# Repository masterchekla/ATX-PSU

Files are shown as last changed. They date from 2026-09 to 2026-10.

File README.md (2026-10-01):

# DIY ATX Bench Power Supply

**Project 1 · Electronics Circuits Laboratory · 091013107**

| Name | Student ID |
|---|---|
| Sirawit Lila | 6809098660047 |
| Pichawee Rungwiboontikul | 6809107660067 |

## 1. Introduction

This was our first power supply project. As second-year students, we studied how an ATX power supply works and used it to build a supply for small circuit experiments. The project combines fixed outputs with an adjustable output in one box.

The fixed outputs are 12 V, 5 V and 3.3 V, with a common GND terminal. A ZK-4KX buck–boost module provides the adjustable output. We also added a 12 V cigarette-lighter power socket, a 5 V LED strip and two status LEDs, while retaining the original PSU fan. We worked together on the project.

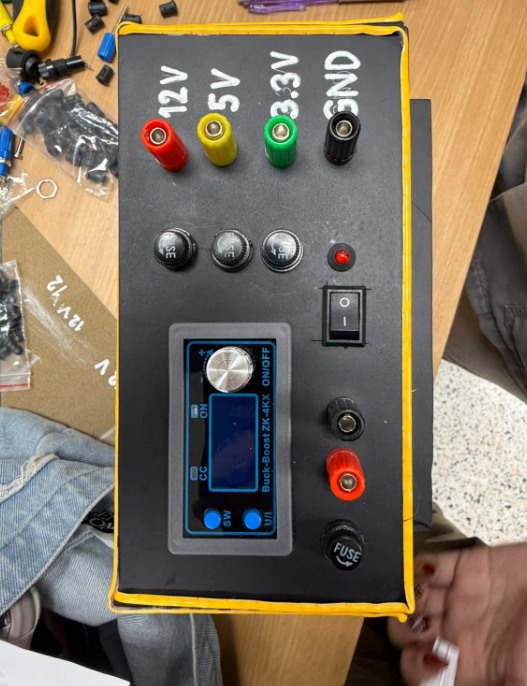
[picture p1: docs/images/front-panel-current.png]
Our power supply front panel


### Source PSU

We used a **PLENTY COMPUTER ATX500WS**, marked **MAX 500 W**. The rear inlet states **AC 230 V Only**. Its nameplate ratings are:

| Output | Current on label |
|---|---:|
| +3.3 V | 22 A |
| +5 V | 14 A |
| +12V1 | 13 A |
| +12V2 | 14 A |
| −12 V | 0.8 A |
| +5VSB | 2.5 A |

The +3.3 V and +5 V rails share a 130 W limit. These are source ratings; each panel branch is also limited by its own fuse, wire and connector. The [source PSU record](docs/source-psu.md) includes the label photographs and the +12V1 label calculation.

## 2. Objectives

- Use the ATX outputs to power small circuits.
- Add voltage adjustment and a current-limit setting using the ZK-4KX.
- Connect the output terminals, switch, indicators and three fixed-output fuses.
- Apply basic voltage, current, resistance and power calculations to the circuit.

## 3. Circuit operation

```mermaid
flowchart LR
    A[ATX PSU] --> B[12 V / 5 V / 3.3 V]
    B --> C[Three fuses]
    C --> D[Fixed output terminals]
    A --> E[12 V to ZK-4KX]
    E --> F[Adjustable output terminals]
    A --> G[12 V socket and 5 V strip]
    A --> H[Purple: green standby LED]
    A --> I[Gray: red power-good LED]
    J[PS_ON switch] --> A
```

### Fixed outputs and fuses

Each fixed positive terminal has its own fuse. F1 serves 12 V, F2 serves 5 V and F3 serves 3.3 V. The black GND terminal is the common return. These three fuses are connected only to the fixed-output branches. The other circuits take their supply directly from the PSU board outputs.

| Output | Front-panel terminal | Standard ATX wire |
|---|---|---|
| +12 V | Red | Yellow |
| +5 V | Yellow | Red |
| +3.3 V | Green | Orange |
| GND / COM | Black | Black |

The panel colors and ATX wire colors are different, so the voltage labels identify the outputs.

### Switch and indicators

The main switch connects the green PS_ON wire to COM to turn on the main outputs. Opening the switch turns them off. The purple +5VSB wire supplies the green standby LED. The gray PWR_OK wire supplies the red LED, which follows the PSU's power-good signal. Each LED has a 1 kΩ series resistor.

Standby power can remain active while the main switch is off. With this arrangement, the green LED can also stay on during main operation. The LED calculations and PWR_OK loading are discussed in Section 5.

### Adjustable output

The ZK-4KX uses the 12 V supply as its input. It can step the voltage up or down and lets us set a current limit. OUT+ connects directly to the positive terminal; the negative terminal connects to OUT−. There is no separate external fuse in this adjustable-output branch. Using OUT− keeps the load current in the module's current-measuring path. It does not electrically isolate the output from the PSU. See the [module instructions](https://aitendo3.sakura.ne.jp/aitendo_data/product_img/power/DC-DC/ZK-4KX/ZK-4KX.pdf) for operation.

### Socket, fan and lighting

J8 is a **12 V panel-mount cigarette-lighter power socket with a protective cap**. The circuit uses its centre contact for +12 V and its outer electrical contact for COM. It provides a connection for 12 V accessories. The original PSU fan provides airflow, and the 5 V LED strip provides lighting around the box.

### Schematic

The schematic shows the low-voltage wiring with the ATX supply on the left and the output terminals on the right. Wires connect the components directly; dots mark connected junctions. J1 groups equivalent ATX signals, with the standard pin numbers retained in the KiCad symbol. These identify connector signals, not physical board pads. The original fan is shown inside the PSU, and the LED returns connect to COM.

Circuit schematic

[KiCad schematic](hardware/diy_atx_psu.kicad_sch) · [Full-size drawing](docs/images/schematic/diy_atx_psu.svg) · [Wire and pin table](docs/wiring-and-protection.md)

## 4. Bill of materials

| Part | Quantity | Function |
|---|---:|---|
| PLENTY ATX500WS power supply | 1 | Fixed rails and standby supply; MAX 500 W label |
| ZK-4KX module | 1 | Adjustable voltage and current limit |
| Fixed output terminals | 4 | 12 V, 5 V, 3.3 V and GND |
| Adjustable output terminals | 2 | OUT+ and OUT− |
| Fixed-output fuses and panel holders | 3 | One per fixed positive output |
| Main switch | 1 | PS_ON control |
| Green LED and red LED | 1 each | Standby and power-good indication |
| 1 kΩ resistors | 2 | LED current control |
| 12 V cigarette-lighter power socket | 1 | Automotive accessory connection |
| Original PSU fan | Included in PSU | Airflow |
| 5 V LED strip | 1 assembly | Lighting |
| Enclosure, wires and mounting parts | 1 set | Assembly and connections |

[Component references](docs/bom.md)

## 5. Calculations

These calculations use the assumptions shown below. The calculated values are not measured test results.

### LED current and resistor power

For a series resistor, `I = (Vs − Vf) / R` and `P = I²R`.

| LED | Calculation assumptions | Calculated current | Resistor power |
|---|---|---:|---:|
| Green | Vs = 5 V, Vf = 2.1 V, R = 1 kΩ | 2.9 mA | 8.41 mW |
| Red | Ideal PWR_OK = 5 V, Vf = 2.0 V, R = 1 kΩ | 3.0 mA | 9.00 mW |

For example, the green LED current is `(5 − 2.1) / 1000 = 0.0029 A`. Both calculated resistor powers are well below 0.25 W.

The gray PWR_OK wire is a status signal. Intel specifies its high voltage with a 0.2 mA load. Our red-LED example gives 3 mA, which is above that specified test load. The actual LED current depends on how much the signal voltage drops under load. Seeing the LED light up does not tell us whether PWR_OK stays within its voltage specification. [Intel PWR_OK specification](https://edc.intel.com/content/www/ca/fr/design/ipla/software-development-platforms/client/platforms/alder-lake-desktop/atx-version-3-0-multi-rail-desktop-platform-po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)

### Converter input current

Using an example output of 15 W and an assumed efficiency of 85%:

`Iin = Pout / (efficiency × Vin)`

At 12 V input, `Iin = 15 / (0.85 × 12) = 1.471 A`.

At 11.2 V input, `Iin = 15 / (0.85 × 11.2) = 1.576 A`.

The input power is `15 / 0.85 = 17.647 W`, giving an estimated loss of `2.647 W`. This shows why input current and cooling matter when using a buck–boost converter.

### Wire resistance and voltage drop

For an example with 0.75 mm² copper wire, 0.5 m outward and 0.5 m returning, use copper resistivity `0.0175 Ω·mm²/m` at 20 °C:

`Rloop = 0.0175 × 1.0 / 0.75 = 0.0233 Ω`

At an assumed 3 A, `Vdrop = IR = 0.070 V` and `Ploss = I²R = 0.210 W`.

Contacts and fuses add resistance. The common return carries the combined return current from the connected fixed-output loads.

### Fuse selection example

For an assumed 1 A continuous load per fixed output and a preliminary 75% loading factor:

`Minimum nominal rating = 1 / 0.75 = 1.33 A`

A 2 A fuse is one possible choice for this example. The final choice also depends on the wire, holder, temperature, startup current and the fuse's ability to interrupt a DC fault. This example does not identify the fuses installed in our box, so the schematic labels them F1–F3 without giving an ampere rating. [Fuse selection reference](https://www.littelfuse.com/assetdocs/fuseology-selection-guide?assetguid=fa4aa360-f6c4-4eec-88a6-3d7ec3fe57d5)

[Detailed calculations](docs/calculations.md)

## 6. Construction

The front panel holds the fixed terminals, adjustable terminals, fuse holders, main switch and ZK-4KX controls. The socket and LED strip complete the assembly; cooling uses the original PSU fan. Internal photographs show the construction stage; the project enclosure is now closed.

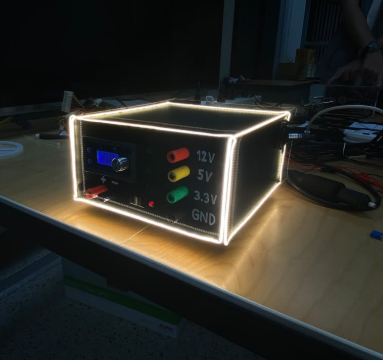
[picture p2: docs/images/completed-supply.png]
Completed supply in operation


[Construction photographs](docs/evidence-register.md) · [Front-panel arrangement](docs/mechanical.md)

## 7. Testing

The following table summarizes the team's reported functional test results. Results are recorded on a pass/fail basis.

| Check | Result |
|---|---|
| Unpowered wiring, polarity and continuity | PASS |
| PS_ON switching and standby/main indication | PASS |
| Startup, repeated-start and no-load operation | PASS |
| Fixed-output operation under load | PASS |
| Adjustable-output operation and current-limit check | PASS |
| Voltage-drop check | PASS |
| Ripple check | PASS |
| Thermal observation | PASS |
| Socket, fan and LED strip operation | PASS |
| Shutdown | PASS |

[Test summary and scope](docs/testing.md)

## 8. Discussion

PS_ON, +5VSB and PWR_OK have different jobs. PS_ON turns on the main outputs, +5VSB supplies standby power, and PWR_OK indicates that the main outputs are ready. The terminal colors on our panel differ from the ATX wire colors, so we use the voltage labels when connecting a load.

The 1 kΩ resistors limit LED current. F1–F3 protect the three fixed-output branches. The adjustable output has no separate external branch fuse. The socket and LED strip have no separate external branch fuses. These branches and the direct PWR_OK LED connection need to be considered when assessing the circuit's protection. The adjustable output is also limited by input power, conversion losses and cooling.

## 9. Operation

1. Start with the main switch off and the adjustable output disabled.
2. Connect AC and observe the green standby indicator.
3. Turn on the main switch and check the selected output voltage.
4. For the adjustable output, set voltage and current limit before connecting a load.
5. Use the labelled terminals and keep the fan and vents clear.
6. After use, disable the outputs, turn off the main switch and disconnect AC.

Disconnect AC and allow stored energy to discharge before changing wiring or fuses. Replace a fuse with a matching type and rating after finding the cause of the fault. The socket is used for accessories; a lighter heating element is outside the project application. [Operating procedure](docs/operation.md)

## 10. Conclusion

We built a bench power supply with 12 V, 5 V and 3.3 V terminals, an adjustable output and a 12 V accessory socket. The functional checks are summarized in Section 7. This first project gave us practice in wiring, mounting parts and calculating current and power. We worked together on the assembly and learned how the ATX control wires and adjustable module work.

## References

- Course handout: *Project 1 – ATX Bench Power Supply*, Chapter 3, Electronics Circuits Laboratory 091013107.
- Intel: [PWR_OK specification](https://edc.intel.com/content/www/ca/fr/design/ipla/software-development-platforms/client/platforms/alder-lake-desktop/atx-version-3-0-multi-rail-desktop-platform-po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) and [ATX voltage regulation](https://edc.intel.com/content/www/us/en/design/ipla/software-development-platforms/client/platforms/alder-lake-desktop/atx-version-3-0-multi-rail-desktop-platform-po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).
- Parts Express: [ZK-4KX module instructions](https://aitendo3.sakura.ne.jp/aitendo_data/product_img/power/DC-DC/ZK-4KX/ZK-4KX.pdf).
- Littelfuse: [Fuseology selection guide](https://www.littelfuse.com/assetdocs/fuseology-selection-guide?assetguid=fa4aa360-f6c4-4eec-88a6-3d7ec3fe57d5).

[Team contribution](docs/contributions.md) · [Project files](docs/repository-guide.md)

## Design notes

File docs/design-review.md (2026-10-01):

# Circuit Discussion

## Outputs and return paths

The fixed outputs share COM. The adjustable load returns through U1 OUT− so its current follows the module's sensing path. The drawing uses standard ATX signal names and the described wiring arrangement.

## Indicators

Green uses +5VSB through 1 kΩ. Red uses PWR_OK through 1 kΩ. An ideal 5 V red-LED supply with a 2 V forward drop gives 3 mA. Intel specifies the PWR_OK high level at a 0.2 mA sourcing load, so this direct-drive arrangement depends on the PSU's particular driver. The signal's loaded voltage determines the actual LED current. [Intel specification](https://edc.intel.com/content/www/ca/fr/design/ipla/software-development-platforms/client/platforms/alder-lake-desktop/atx-version-3-0-multi-rail-desktop-platform-po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)

## Protection

F1–F3 serve the three fixed positive outputs only. The adjustable output connects directly from OUT+ to its positive terminal and has no separate external fuse. The converter input, socket and strip connect to PSU outputs; the fan is part of the original PSU assembly. Protection must be coordinated with each branch's wire and components; the main source's protection does not by itself establish protection for every smaller wire. The fuse example uses an assumed 1 A load per fixed branch.

## Conversion losses

The converter input current follows input power. At an assumed 85% efficiency, a 15 W output requires 17.647 W input and produces about 2.647 W loss. Cooling and the combined load on the source therefore affect usable output power.

## Scope of the drawing

The schematic represents low-voltage distribution and control. The PSU and converter are functional blocks. Their internal circuits and mains wiring are outside this drawing. Connector and module symbols describe connectivity; ERC does not model the PWR_OK driver's current capability or fuse-clearing energy.

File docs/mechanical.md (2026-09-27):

# Mechanical Arrangement

The front panel groups the fixed terminals above the adjustable-output controls. Three fuse holders serve the fixed outputs. The main switch and status indicator provide the panel controls, while the fan and LED strip support airflow and lighting.

Current front panel

Front-panel arrangement

*Layout illustration based on the construction photographs; not to scale.*

The enclosure is closed for operation. Insulation around terminal backs, secure wire routing, strain relief and clearance from fan blades are important construction details. The adjustable return is routed to the module OUT−, and the shared COM path carries the combined fixed-output return current.

[Construction photographs](evidence-register.md)

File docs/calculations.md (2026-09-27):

# Calculation Notes

These examples use the assumptions stated below. The functional test summary is in [Testing](testing.md).

## 1. LED resistors

`I = (Vs − Vf) / R` and `PR = (Vs − Vf)² / R`.

Nominal R = 1 kΩ. Assume Vf = 2.1 V for green and 2.0 V for red. The tolerance examples use R = 950 Ω and Vf = 1.8 V, with 5.25 V for standby and an ideal 5 V for PWR_OK.

| Example | Current (mA) | Resistor power (mW) |
|---|---:|---:|
| Green, nominal 5 V | 2.9000 | 8.4100 |
| Red, ideal 5 V signal | 3.0000 | 9.0000 |
| Red, ideal 2.4 V signal | 0.4000 | 0.1600 |
| Red, tolerance example | 3.3684 | 10.7789 |
| Green, tolerance example | 3.6316 | 12.5289 |

A 0.25 W resistor has ample power margin in these examples. The red-LED figures assume an ideal signal voltage. Intel specifies PWR_OK high at a 0.2 mA sourcing load; the ideal 5 V example demands 3 mA, or 15 times that condition. Actual LED current depends on the PSU driver and loaded voltage. The 0.2 mA specification is a guaranteed test condition, not an absolute damage limit. [PWR_OK specification](https://edc.intel.com/content/www/ca/fr/design/ipla/software-development-platforms/client/platforms/alder-lake-desktop/atx-version-3-0-multi-rail-desktop-platform-po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)

## 2. Converter input and loss

Assume Pout = 15 W and efficiency = 85%.

`Pin = Pout / efficiency = 17.647 W`

At Vin = 11.2 V, `Iin = Pin / Vin = 1.576 A`.

At Vin = 12 V, `Iin = 15 / (0.85 × 12) = 1.471 A`.

`Ploss = Pin − Pout = 2.647 W`.

These are steady-state examples. Startup current and idle consumption are separate contributions. Usable output also depends on source, wire, module and thermal ratings.

## 3. Wire voltage drop

Assume copper resistivity = 0.0175 Ω·mm²/m at 20 °C, cross-section = 0.75 mm², and length = 0.5 m each way. The total circuit length is 1.0 m.

`Rloop = 0.0175 × 1.0 / 0.75 = 0.023333 Ω`

At an assumed 3 A:

- Voltage drop = 0.070 V.
- Wire power loss = 0.210 W.
- Drop relative to 3.3 V = 2.12%.

Contact resistance and fuse resistance add to this result. Wire ampacity also depends on insulation, temperature, routing and termination quality.

## 4. Fixed-output fuse example

Assume a continuous load of 1 A per fixed output and a preliminary loading factor of 75%.

| Branch | Assumed current (A) | I / 0.75 (A) | Calculation candidate (A) |
|---|---:|---:|---:|
| F1 | 1.00 | 1.333 | 2 |
| F2 | 1.00 | 1.333 | 2 |
| F3 | 1.00 | 1.333 | 2 |

The 2 A values belong to this selection example, rather than a fitted-fuse record. The exact part must coordinate with the wire, holder, load, ambient temperature and fault current. See [Wiring and Protection](wiring-and-protection.md).

## 5. Source current budget

`I12 = I12_terminal + Isocket + Iconverter_input`

`I5 = I5_terminal + Istrip`

`I3.3 = I3.3_terminal`

`I5VSB = Igreen_LED + other standby loads`

The original fan belongs to the PSU internal circuit and is outside the external branch-current sum. The red LED loads PWR_OK separately. The common return carries the combined current of its connected branches. Total loading is subject to the PSU's individual-rail and combined-power ratings.

## 6. Useful test formulas

- Load power: `P = V × I`.
- Branch drop: `Vdrop = Vsource − Vterminal`.
- Regulation change: `100 × (Vloaded − Vno-load) / Vno-load`.
- Converter efficiency: `100 × (Vout × Iout) / (Vin × Iin)`.
- Temperature rise: `Thotspot − Tambient`.

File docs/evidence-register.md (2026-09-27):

# Construction Photographs

The photographs show the parts and assembly process. Internal views were taken during construction; the project enclosure is now closed.

| Photograph | Description |
|---|---|
| [IMG_4238](images/IMG_4238.jpg) | Internal construction view: PSU board, wiring and mechanical arrangement. |
| [IMG_4239](images/IMG_4239.jpg) | Internal construction view: PSU board, wiring and mechanical arrangement. |
| [IMG_4240](images/IMG_4240.jpg) | Internal construction view: PSU board, wiring and mechanical arrangement. |
| [IMG_4241](images/IMG_4241.jpg) | Internal construction view: PSU board, wiring and mechanical arrangement. |
| [IMG_4242](images/IMG_4242.jpg) | Internal construction view: PSU board, wiring and mechanical arrangement. |
| [IMG_4243](images/IMG_4243.jpg) | Internal construction view: PSU board, wiring and mechanical arrangement. |
| [IMG_4244](images/IMG_4244.jpg) | Internal construction view: PSU board, wiring and mechanical arrangement. |
| [IMG_4245](images/IMG_4245.jpg) | Internal construction view: PSU board, wiring and mechanical arrangement. |
| [IMG_4246](images/IMG_4246.jpg) | Internal construction view: PSU board, wiring and mechanical arrangement. |
| [IMG_4295](images/IMG_4295.jpg) | Internal construction view: PSU board, wiring and mechanical arrangement. |
| [IMG_4296](images/IMG_4296.jpg) | Internal construction view: PSU board, wiring and mechanical arrangement. |
| [IMG_4297](images/IMG_4297.jpg) | Internal construction view: PSU board, wiring and mechanical arrangement. |
| [IMG_4298](images/IMG_4298.jpg) | Internal construction view: PSU board, wiring and mechanical arrangement. |
| [IMG_4303](images/IMG_4303.jpg) | Enclosure and illuminated LED strip. |
| [IMG_4305](images/IMG_4305.jpg) | Heat-shrink sleeve and insulation material. |
| [IMG_4306](images/IMG_4306.jpg) | Fuse-holder cap. |
| [IMG_4307](images/IMG_4307.jpg) | Green LED parts. |
| [IMG_4308](images/IMG_4308.jpg) | Red LED parts. |
| [IMG_4309](images/IMG_4309.jpg) | Drill press used during construction. |
| [IMG_4310](images/IMG_4310.jpg) | Component parts in packaging. |
| [IMG_4311](images/IMG_4311.jpg) | Construction consumable bottle. |
| [IMG_4312](images/IMG_4312.jpg) | Rocker switch part. |
| [IMG_4313](images/IMG_4313.jpg) | Blue binding-post part. |
| [IMG_4314](images/IMG_4314.jpg) | Front panel with fixed terminals, fuse holders, ZK-4KX and adjustable terminals. |
| [IMG_4315](images/IMG_4315.jpg) | Red binding-post part. |
| [IMG_4316](images/IMG_4316.jpg) | Panel fuse-holder part. |

[Functional test summary](testing.md)

## Source identification and completed assembly

| Photograph | Description |
|---|---|
| [PSU nameplate](images/psu-nameplate.png) | PLENTY COMPUTER ATX500WS and output ratings |
| [AC input](images/psu-ac-input.png) | AC 230 V Only inlet and original fan |
| [Current front panel](images/front-panel-current.png) | Black GND terminal and adjustable-output section |
| [Completed supply](images/completed-supply.png) | Closed enclosure with LED strip illuminated |

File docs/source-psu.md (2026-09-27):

# Source Power Supply

The source is a **PLENTY COMPUTER ATX500WS** switching power supply. Its main label states **MAX 500 W**. The rear AC inlet is marked **AC 230 V Only**; this is the input marking used for this unit.

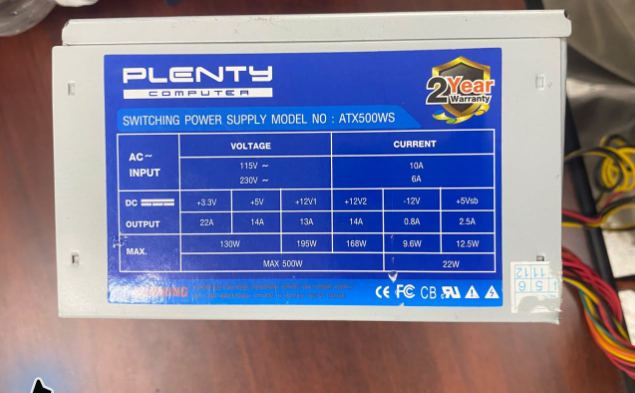
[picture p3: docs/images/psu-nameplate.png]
PLENTY ATX500WS label


## DC output ratings

| Output | Current on label |
|---|---:|
| +3.3 V | 22 A |
| +5 V | 14 A |
| +12V1 | 13 A |
| +12V2 | 14 A |
| −12 V | 0.8 A |
| +5VSB | 2.5 A |

The label gives a combined 130 W for +3.3 V and +5 V, 168 W for +12V2, 9.6 W for −12 V, and 12.5 W for +5VSB. It also shows a combined 22 W for −12 V and +5VSB.

The +12V1 column contains an inconsistency: it lists 13 A and 195 W, while `12 × 13 = 156 W`. Current calculations therefore use 13 A rather than deriving a higher current from 195 W. The two +12 V groups are kept separate in the source rating table; the project does not join them to claim a combined terminal current.

These are PSU nameplate ratings. The current at a panel output also depends on its fuse, wire and connector. The MAX 500 W marking is not a 500 W rating for the adjustable output.

## AC input

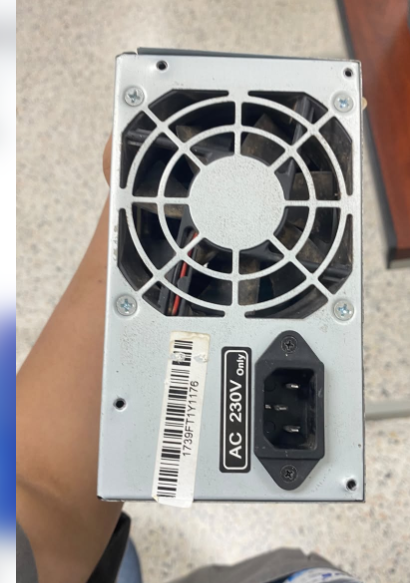
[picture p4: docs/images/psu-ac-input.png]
Rear AC inlet and fan


The main label contains 115 V / 10 A and 230 V / 6 A entries, while the rear inlet explicitly specifies AC 230 V Only. The rear marking identifies the operating input for this unit.

## Cooling

The fan belongs to the PSU's original internal circuit. It is included as part of the source assembly, rather than as an added external 12 V load. The schematic shows it as a functional part of the PSU without assigning an internal supply wire.

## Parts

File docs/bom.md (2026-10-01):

# Bill of Materials

| Reference | Quantity | Component | Function |
|---|---:|---|---|
| PSU1 | 1 | PLENTY COMPUTER ATX500WS | Fixed rails and standby supply |
| J2–J5 | 4 | Fixed binding posts | Red 12 V, yellow 5 V, green 3.3 V, black COM |
| J6–J7 | 2 | Adjustable binding posts | Module OUT+ and OUT− |
| U1 | 1 | ZK-4KX buck–boost module | Voltage adjustment and current limiting |
| F1–F3 | 3 | Fuses with panel holders | One per fixed positive output |
| SW1 | 1 | Maintained switch | Connects PS_ON to COM |
| D1 | 1 | Green LED | Purple +5VSB indication |
| D2 | 1 | Red LED | Gray PWR_OK indication |
| R1–R2 | 2 | 1 kΩ resistors | Series LED resistors |
| J8 | 1 | 12 V panel-mount cigarette-lighter power socket with cap | Accessory output |
| J9 | 1 assembly | 5 V LED strip and connection | Enclosure lighting |
| M1 | Included in PSU | Original internal fan | Airflow |
| Enclosure and mounting parts | 1 set | Box, fasteners and supports | Mechanical assembly |
| Wiring and insulation | 1 set | Wires, terminals and insulation | Electrical connections |

J1 is the schematic's ATX signal reference. TP1 marks the PWR_OK measurement node; neither represents an additional purchased part.

Fuse selection and resistor power examples are in the [calculation section](calculations.md). The BOM lists the assembly components, while that section explains the design assumptions.

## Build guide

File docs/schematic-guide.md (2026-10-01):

# Circuit Drawing Guide

[Open the schematic image](images/schematic/diy_atx_psu.svg).

| Position | Circuit |
|---|---|
| Left | J1 ATX supply, with the original fan M1 shown inside |
| Upper right | F1–F3 and the 12 V, 5 V and 3.3 V terminals |
| Centre | U1 ZK-4KX and the adjustable terminals |
| Lower centre | R1/D1 standby indicator and R2/D2 power-good indicator |
| Lower right | J8 12 V socket and J9 5 V LED strip |
| Bottom | SW1 PS_ON switch and the COM return to black terminal J5 |

Follow the drawn wires from the supply to each load and its return. A dot marks a junction; crossing wires without a dot are not connected. The adjustable negative terminal J7 returns to the module's OUT− pin rather than joining the external COM bus directly.

J1 groups equivalent signals from the conventional motherboard-side 24-pin ATX map. The pin numbers are retained in the KiCad symbol and listed in the [wire and pin table](wiring-and-protection.md). This is a signal map, not a physical view of the connector or PSU board pads.

F1–F3 are the three fixed-output fuses. The adjustable positive terminal connects directly to OUT+, with no separate external fuse. Fuse-selection calculations are in the report. R1 and R2 are the 1 kΩ LED resistors. The original PSU fan is shown within J1 because its internal wiring is not part of the external distribution drawing.

The source and module are represented by their external signals. See the [circuit discussion](design-review.md) for the return paths, PWR_OK loading and branch protection.

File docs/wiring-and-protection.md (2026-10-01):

# Wiring and Protection

## Standard ATX signal map

The table follows course handout Section 3.4.1. Pin numbers refer to the motherboard-side 24-pin connector. The project uses these names as a logical signal reference for the PSU board connections.

| Pin | Signal | Conventional color | Pin | Signal | Conventional color |
|---:|---|---|---:|---|---|
| 1 | +3.3 V | Orange | 13 | +3.3 V / optional sense | Orange / brown sense |
| 2 | +3.3 V | Orange | 14 | −12 V | Blue |
| 3 | COM | Black | 15 | COM | Black |
| 4 | +5 V | Red | 16 | PS_ON active low | Green |
| 5 | COM | Black | 17 | COM | Black |
| 6 | +5 V | Red | 18 | COM | Black |
| 7 | COM | Black | 19 | COM | Black |
| 8 | PWR_OK logic | Gray | 20 | Reserved / NC | None |
| 9 | +5VSB | Purple | 21 | +5 V | Red |
| 10 | +12 V | Yellow | 22 | +5 V | Red |
| 11 | +12 V | Yellow | 23 | +5 V | Red |
| 12 | +3.3 V | Orange | 24 | COM | Black |

Pin 20 follows the handout's logical table: reserved / no connection. Original sense connections remain part of the source circuit. Connector mating-face and wire-entry views are mirrored, so the logical table is not a physical connector-view drawing.

## Project connections

| Source | Destination |
|---|---|
| +12 V | F1 → red fixed terminal; direct feeds to ZK-4KX and J8 socket |
| +5 V | F2 → yellow fixed terminal; LED strip |
| +3.3 V | F3 → green fixed terminal |
| COM | Black terminal and supply returns |
| Purple +5VSB | R1 → green LED → COM |
| Gray PWR_OK | R2 → red LED → COM |
| Green PS_ON | Main switch → COM |
| U1 OUT+ | Adjustable positive terminal (direct connection) |
| U1 OUT− | Adjustable negative terminal |

The original fan remains within the PSU assembly. F1–F3 serve the fixed outputs. OUT+ connects directly to the adjustable positive terminal, without a separate external fuse. The socket, strip and indicators have no separate external branch fuse in this arrangement.

## Fuse calculation basis

For the example 1 A continuous load on each fixed output, a preliminary 75% loading factor gives `1 / 0.75 = 1.33 A`. A 2 A component is a candidate within that example. This calculation is separate from the fitted component record.

The final selection depends on the exact fuse's time-current curve, DC voltage and breaking ratings, ambient temperature, inrush and protected wire. Fuse rating is not an adjustable current limit. Place the fuse in the positive branch, with the common return continuous. [Littelfuse selection guide](https://www.littelfuse.com/assetdocs/fuseology-selection-guide?assetguid=fa4aa360-f6c4-4eec-88a6-3d7ec3fe57d5)

## Control and return paths

PWR_OK is a status signal, while PS_ON is an input control. The standby supply can remain active when the main switch is off. The adjustable output returns to U1 OUT−; the fixed outputs use COM. A shared COM wire carries the total return current from its connected loads.

[PLENTY ATX500WS source ratings](source-psu.md)

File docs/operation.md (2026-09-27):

# Operating Procedure

## Before connection

Confirm the output polarity, closed enclosure, clear ventilation and load rating. Select loads within the source and component ratings. The report's calculation examples do not set a maximum hardware load.

## Startup

1. Remove external loads, set the maintained main switch OFF and disable the adjustable output.
2. Connect meter leads while AC is disconnected. Use insulated clips and a suitable voltage range.
3. Connect AC through the original PSU input. Check standby indication; +5VSB can be live while main outputs are off.
4. Close the PS_ON switch and check the selected fixed output. The red indicator follows gray PWR_OK; green remains on while purple +5VSB is present. An illuminated LED does not replace checking the selected output voltage.
5. Set the adjustable voltage and current limit, then verify the voltage at OUT+/OUT− using a DMM.
6. Disable output before connecting a load. Restore power only with insulated connections and a load within verified branch and combined-source limits.

## During operation

Use the written voltage labels; panel colors differ from ATX wire colors. Fixed rails have no user-adjustable current limit. Keep the adjustable return separate from the fixed COM wiring and avoid unintended earth connections through test equipment. Do not connect different rails in parallel or use the ±12 V rails as a general-purpose 24 V supply.

J8 is a 12 V panel-mount cigarette-lighter power socket with a protective cap for automotive accessories. Its connector shape does not establish a 10 A or 15 A current rating. A lighter heating insert is outside the documented use. The LED strip requires 5 V. Match the fan to its own voltage/current specification and retain the original PSU fan circuit.

Stop for unstable output, unexpected shutdown, damaged insulation, excessive heat or unusual odor. Investigate with AC removed; do not repeatedly cycle a fault or increase the fuse rating.

## Shutdown and fuse replacement

Disable the converter output, open the maintained PS_ON switch, switch off the PSU input and disconnect AC. Wait for stored energy to discharge and verify the relevant low-voltage points before touching wiring. Disconnect loads and allow cooling before storage.

For a blown fuse, identify the cause before replacement. Use the confirmed ampere rating, time characteristic, DC voltage rating, breaking capacity and physical size. Do not bridge the holder. Recheck wiring and polarity before returning the unit to service.

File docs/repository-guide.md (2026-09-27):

# Project Files

Open `DIY-ATX-PSU.code-workspace` in VS Code. Open `README.md` and use Ctrl+Shift+V for the report preview. GitHub renders the relative image links and Mermaid block diagram.

Open `hardware/diy_atx_psu.kicad_pro` in KiCad. The schematic uses its adjacent `Project.kicad_sym` and `sym-lib-table`. It documents a panel/harness design, not a PCB layout. The [reading guide](schematic-guide.md) explains the sheet sections and symbols.

## Reading the report

Start with [README](../README.md) for the circuit explanation, calculations, parts list and conclusion. The `docs` folder contains the supporting notes and construction photographs.

Open [the schematic image](images/schematic/diy_atx_psu.svg) to view the circuit in a browser. Download the repository and open `hardware/diy_atx_psu.kicad_pro` to view or edit it in KiCad. Keep the files in `hardware` together so KiCad can find the symbol library.

The [test summary](testing.md) records the team's reported functional test results.

## Photographs

The construction photographs are in `docs/images`. The [photo index](evidence-register.md) describes each image.

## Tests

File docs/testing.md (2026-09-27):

# Functional Test Summary

The table records the team's reported test outcomes for the completed prototype. It is a qualitative pass/fail summary; the calculations in this report are theoretical examples.

| Check | Result |
|---|---|
| Unpowered wiring, polarity and continuity | PASS |
| PS_ON switching and standby/main indication | PASS |
| Startup, repeated-start and no-load operation | PASS |
| Fixed-output operation under load | PASS |
| Adjustable-output operation and current-limit check | PASS |
| Voltage-drop check | PASS |
| Ripple check | PASS |
| Thermal observation | PASS |
| Socket, fan and LED strip operation | PASS |
| Shutdown | PASS |

## Test scope

The checks cover the assembled 12 V, 5 V and 3.3 V outputs, adjustable output, controls and accessories. PASS describes the reported outcome of each check rather than a numerical maximum rating or full ATX compliance result.

The direct PWR_OK LED connection has the signal-loading limitation discussed in the [circuit discussion](design-review.md). Functional indication and signal-drive margin are different quantities. Fuse selection is analysed separately in the [calculation notes](calculations.md).

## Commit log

2026-09-27 Add circuit
    [diy_atx_psu.kicad_sch]
2026-10-01 Update circuit
    [diy_atx_psu.kicad_sch]
2026-10-01 Correct fuse count
2026-10-01 Update fuse notes
2026-10-01 Update schematic
    [diy_atx_psu.kicad_sch]
2026-10-01 Update schematic image
2026-10-01 Remove unused test point
    [diy_atx_psu.kicad_sch]
